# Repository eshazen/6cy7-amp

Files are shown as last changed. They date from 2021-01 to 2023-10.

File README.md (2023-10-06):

# 6CY7-amp

This is a low power single-ended tridode (SET) hi-fi amp for the
workshop.  It is essentially a build of the Cascade Tubes "Zebrawood"
amp: https://www.cascadetubes.com/the-6cy7-v2-0-zebrawood-amp/.  I'm
using transformers from MusicalPowerSupplies.com.

PCB design here is 388 x 194mm.  It's the standard 1oz copper, 1.6mm thick.
Everything is on the PCB.  Mounted on a wooden base on 3/4 inch standoffs (including standoffs under the PT).  Case is 20mm 80/20 T-slot rail with acrylic side panels.  Complete overkill, but I like the industrial look!

<table>
  <tr><td>
    <img src="https://github.com/eshazen/6cy7-amp/blob/main/pix/enclosure_done.jpg" width=500">
  <tr><td>

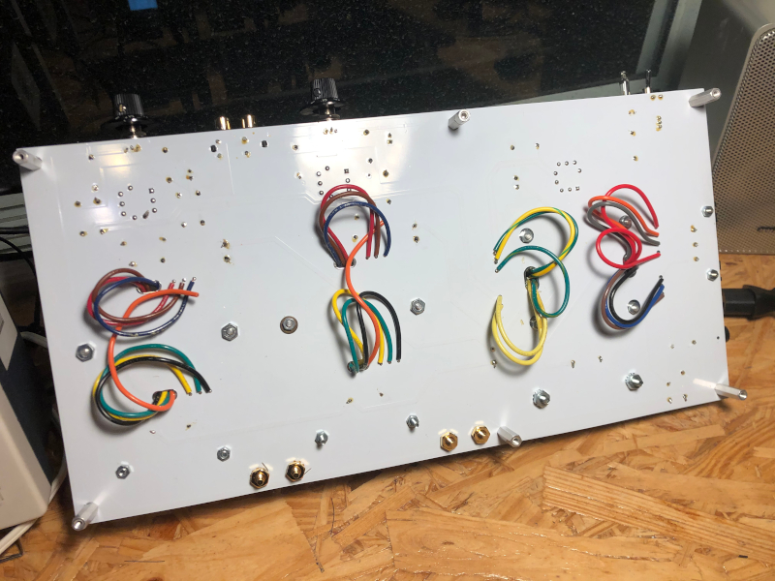
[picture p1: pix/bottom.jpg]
  
  <td>


</table>

## Want to build one?

See https://github.com/eshazen/6cy7-amp/blob/main/BuildNotes.md

## News

**2021-02-20**

Working on a second PCB.  MPS has a long lead time on the PT.  
Ordered two OT8SE OTs and one of these:  AS-1T175 -- (2x 175V @ 280mA, 2x 6.3V @ 3A).
This thing is toroidal, 3.9" dia, 2" h.  Plan to mount it vertically on a bracket above the PCB.

**2021-01-15**

It's done!  Sounds great!  A couple of concerns:

I forgot the R/C filter for the preamp stage B+.  No audible defects due to this, but if someone else wants
to consider using this PCB design the R+C should be added.

One of the "NOS" 6CY7s (a Tung-Sol, made in USA) ran very hot (right at 32mA, 5.4W plate diss.) with
the 1k cathode resistor.  Swapped it for another of indeterminate make and it is fine.  Both channels
now around 27mA (4.6W).

**2021-01-03**

* 2/29/20: Iron ordered from MusicalPowerSupplies.com for a ~ 1/15/21 ship date
* 1/2/21: Parts ordered from DigiKey and Antique Electronic Supply
* 1/3/21: PCBs ordered from JLC (white soldermask, black silkscreen, cool, eh?)

Total spent with some spare stuff thrown in ~ US $350.00.  Hope to have it running by end of January!

**Speakers** Need some small bookshelf speakers to go with it.  Will test the amp with what I have lying around before making any decisions.  The easiest would be to buy another pair of Minimus-7's and apply the 'Zilch' crossover mod.

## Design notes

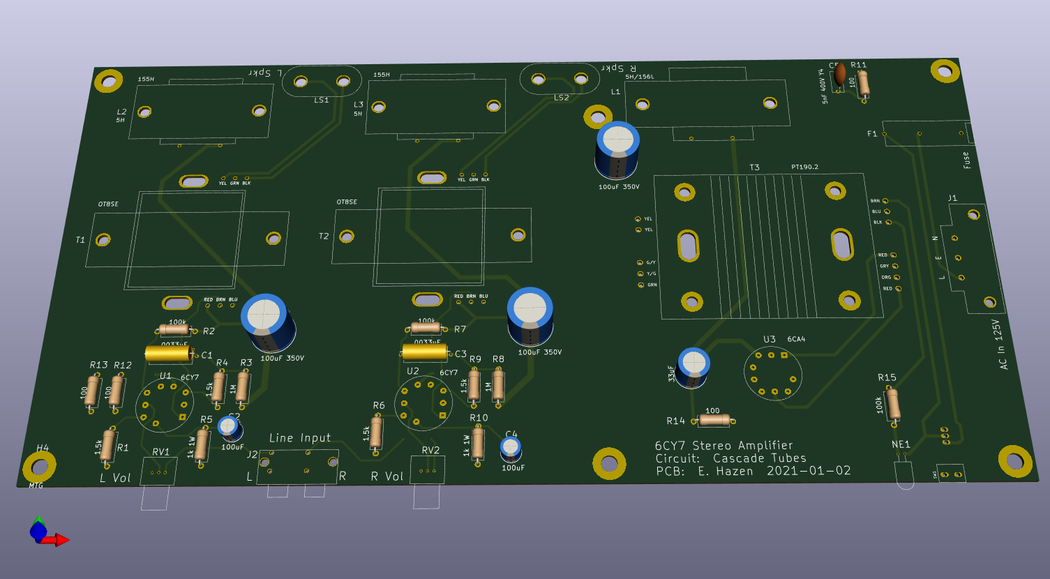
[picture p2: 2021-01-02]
pix/pcb_3d_amp.png

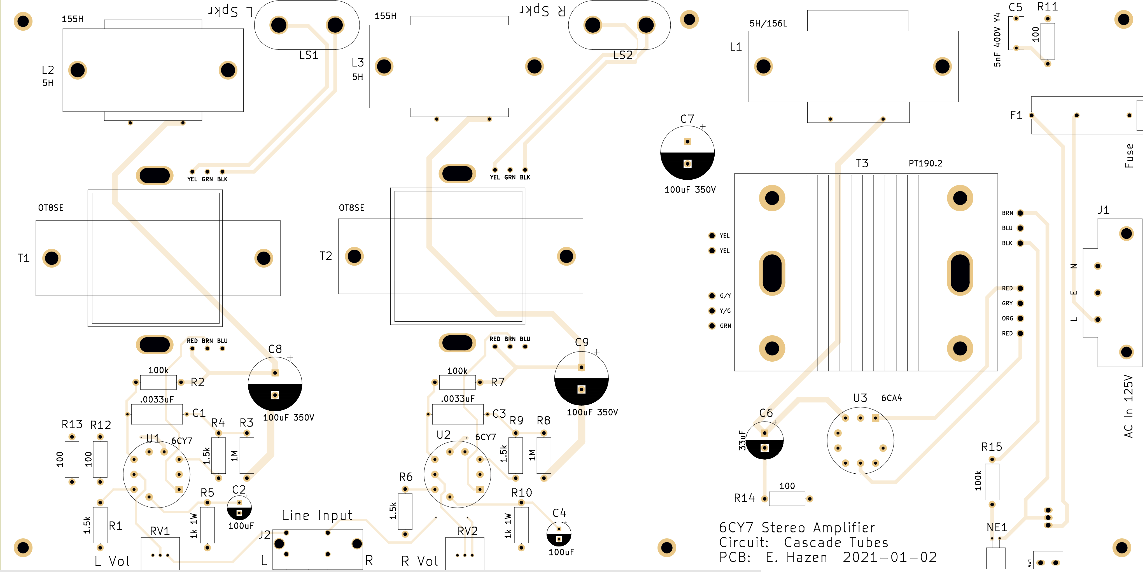
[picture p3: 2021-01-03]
pix/layout_preview.png

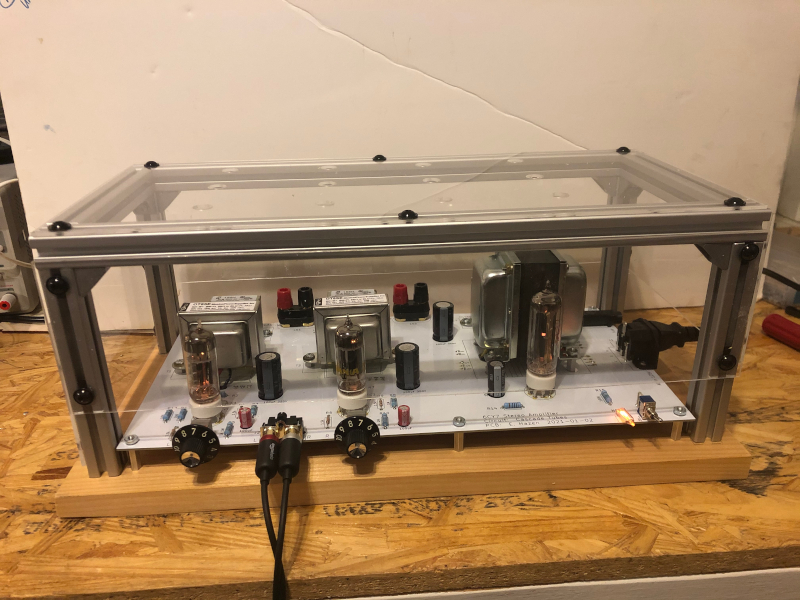
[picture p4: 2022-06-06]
pix/enclosure_done.jpg

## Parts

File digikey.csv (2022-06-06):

Quan | P/N | Ref
3 | Socket_P-ST9-221G | U1 U2
2 | Socket_P-ST9-221G | U3
3 | 1572-1715-ND | C1 C3
3 | 732-8666-1-ND | C2 C4
2 | 125LD50-R-ND | C5
2 | 493-12996-1-ND | C6
4 | 1189-4068-ND | C7 C8 C9
2 | 283-2709-ND | F1
2 | 486-1007-ND | J1
2 | SC1858-ND | J2
2 | HM3516-ND | L1
3 | 36-4109-ND | LS1 LS2
2 | A1A-ND | NE1
5 | BC4520CT-ND | R1 R4 R6 R9
5 | BC4517CT-ND | R11 R12 R13 R14
4 | BC4520CT-ND | R2 R7 R15
3 | BC4521CT-ND | R3 R8
3 | BC4518CT-ND | R5 R10
3 | 987-1330-ND | RV1 RV2
2 | 563-1727-ND | SW1

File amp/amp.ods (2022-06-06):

Reference | Quantity | Value | Footprint | Datasheet | CatNo | Vendor | Quan | P/N | Ref
U1 U2 | 2 | 6CY7 | Valve:Valve_Noval_P |  | Socket_P-ST9-221G | AES | 3 | Socket_P-ST9-221G | U1 U2
U3 | 1 | 6CA4 | Valve:Valve_Noval_P |  | Socket_P-ST9-221G | AES | 2 | Socket_P-ST9-221G | U3
C1 C3 | 2 | .0033uF | Capacitor_THT:C_Axial_L17.0mm_D6.5mm_P20.00mm_Horizontal | ~ | 1572-1715-ND | DigiKey | 2 | 1572-1715-ND | C1 C3
C2 C4 | 2 | 100uF | Capacitor_THT:CP_Radial_D8.0mm_P3.50mm | ~ | 732-8666-1-ND | DigiKey | 2 | 732-8666-1-ND | C2 C4
C5 | 1 | 5nF 400V Y4 | Capacitor_THT:C_Disc_D11.0mm_W5.0mm_P10.00mm | ~ | 125LD50-R-ND | DigiKey | 1 | 125LD50-R-ND | C5
C6 | 1 | 33uF | Capacitor_THT:CP_Radial_D12.5mm_P5.00mm | ~ | 493-12996-1-ND | DigiKey | 2 | 493-12996-1-ND | C6
C7 C8 C9 | 3 | 100uF 350V | Capacitor_THT:CP_Radial_D18.0mm_P7.50mm | ~ | 1189-4068-ND | DigiKey | 4 | 1189-4068-ND | C7 C8 C9
F1 | 1 | Fuse | HBH_fuse_holder:HBH-I-R | ~ | 283-2709-ND | DigiKey | 2 | 283-2709-ND | F1
J1 | 1 | Conn_01x05 | GSP1_power_entry:GSP1.8101.1 | ~ | 486-1007-ND | DigiKey | 2 | 486-1007-ND | J1
J2 | 1 | DUAL_RCA | RCA_jack:PJRAS2X1S01AUX |  | SC1858-ND | DigiKey | 2 | SC1858-ND | J2
L1 | 1 | 5H/156L | Hammond-L:156L | ~ | HM3516-ND | DigiKey | 2 | HM3516-ND | L1
L2 L3 | 2 | 5H | Hammond-L:155H | ~ | HM3512-ND | DigiKey | 3 | HM3512-ND | L2 L3
LS1 LS2 | 2 | Speaker | BindingPost:Keystone_4109 | ~ | 36-4109-ND | DigiKey | 3 | 36-4109-ND | LS1 LS2
NE1 | 1 | A1A | neon:A1A | ~ | A1A-ND | DigiKey | 2 | A1A-ND | NE1
R1 R4 R6 R9 | 4 | 1.5k | Resistor_THT:R_Axial_DIN0414_L11.9mm_D4.5mm_P15.24mm_Horizontal | ~ | BC4526CT-ND | DigiKey | 5 | BC4526CT-ND | R1 R4 R6 R9
R11 R12 R13 R14 | 4 | 100 | Resistor_THT:R_Axial_DIN0414_L11.9mm_D4.5mm_P15.24mm_Horizontal | ~ | BC4517CT-ND | DigiKey | 5 | BC4517CT-ND | R11 R12 R13 R14
R2 R7 R15 | 3 | 100k | Resistor_THT:R_Axial_DIN0414_L11.9mm_D4.5mm_P15.24mm_Horizontal | ~ | BC4520CT-ND | DigiKey | 4 | BC4520CT-ND | R2 R7 R15
R3 R8 | 2 | 1M | Resistor_THT:R_Axial_DIN0414_L11.9mm_D4.5mm_P15.24mm_Horizontal | ~ | BC4521CT-ND | DigiKey | 3 | BC4521CT-ND | R3 R8
R5 R10 | 2 | 1k 1W | Resistor_THT:R_Axial_DIN0414_L11.9mm_D4.5mm_P15.24mm_Horizontal | ~ | BC4518CT-ND | DigiKey | 3 | BC4518CT-ND | R5 R10
RV1 RV2 | 2 | 100k_audio | POT:P260P-D1BS3CA | ~ | 987-1330-ND | DigiKey | 3 | 987-1330-ND | RV1 RV2
SW1 | 1 | SW_SPST_GND | Switch_8GA:8GA1016-Z | ~ | 563-1727-ND | DigiKey | 2 | 563-1727-ND | SW1
H1 H2 H3 H4 H5 H6 | 6 | MTG | MountingHole:MountingHole_6.4mm_M6_Pad | ~ |  |  | 7 | 0 | H1 H2 H3 H4 H5 H6
T1 T2 | 2 | Transformer_1P_1S | OT8SE:OT8SE | ~ | OT8SE |  | 3 | OT8SE | T1 T2
T3 | 1 | Transformer_PT190.2 | PT190_2:PT190_2 | ~ |  |  | 2 | 0 | T3
Notes:
2/13/21 – Fix CatNo for R1… for 1.5K

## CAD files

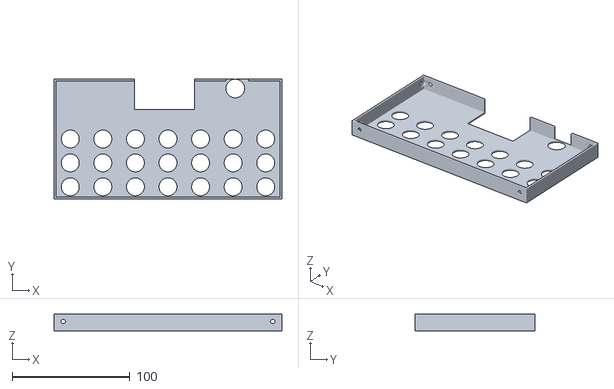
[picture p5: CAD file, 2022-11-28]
case/right_side.stl
193.7 x 101.6 x 14.2

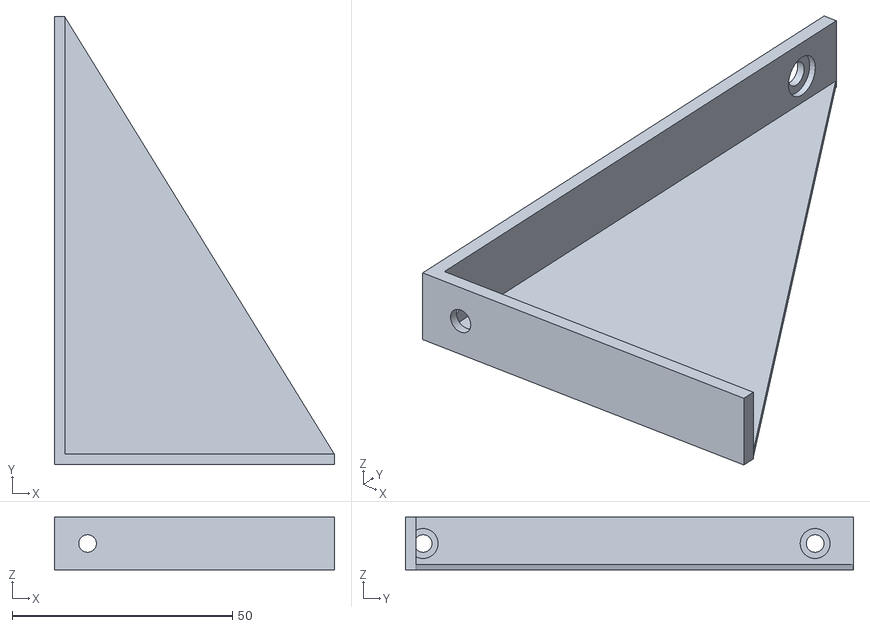
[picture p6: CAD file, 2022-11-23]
case/bracket4.stl
63.5 x 101.6 x 12.0

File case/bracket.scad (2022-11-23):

//
// mounting bracket for Olof's front panel (need 2)
//


e = 0.1;
$fn = 32;

mm = 25.4;

pcb_setback = 7.5;			/* PCB hole from edge */
front_raise = 4.0;			/* panel hole from top surf of pcb */
hole_dia = 4.0;
head_dia = 6.8;			/* 6-32 screw head diameter */

head_dep = 2;			/* relief depth */

front_space = 3.5*mm;		/* front panel hole spacing */

bracket_wid = 12;
bracket_thk = 2.4;
side_thk = 1.2;

// short version for test print
// bracket_pcb_len = 1*mm;	/* length along pcb */
// bracket_panel_hgt = 1*mm;	/* height behind panel */

bracket_pcb_len = 2.5*mm;	/* length along pcb */
bracket_panel_hgt = 4.0*mm;	/* height behind panel */

module base() {

     cube( [bracket_pcb_len, bracket_thk, bracket_wid]);
     cube( [bracket_thk, bracket_panel_hgt, bracket_wid]);

     linear_extrude( height=side_thk, center=false, convexity=10) {
	  polygon( [[bracket_pcb_len, bracket_thk-e],
		   [bracket_thk-e, bracket_panel_hgt],
		   [0,0]]);
     }
}


module bracket() {

     difference() {
//     {
	  base();

	  // home for PCB mount
	  translate( [pcb_setback, -e, bracket_wid/2]) {
	       rotate( [-90, 0, 0]) {
		    cylinder( d=hole_dia, h=10);
		    translate( [0, 0, 1.6]) {
			 $fn = 6;
			 cylinder( d=9, h=head_dep+bracket_thk/2);
		    }
	       }
	  }

	  // hole for FP mount
	  translate( [bracket_thk+e, front_raise, bracket_wid/2]) {
	       rotate( [-90, 0, 90]) {
		    cylinder( d=hole_dia, h=10);
		    translate( [0, 0, -head_dep])
		    cylinder( d=head_dia, h=head_dep+bracket_thk/2);
	       }
	  }

	  // hole for FP mount
	  translate( [bracket_thk+e, front_raise+front_space, bracket_wid/2]) {
	       rotate( [-90, 0, 90]) {
		    cylinder( d=hole_dia, h=10);
		    translate( [0, 0, -head_dep])
		    cylinder( d=head_dia, h=head_dep+bracket_thk/2);
	       }
	  }


     }
}

bracket();

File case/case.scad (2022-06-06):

// dimensions
wid = 16;
dep = 8;
hgt = 7;

fb_hgt = 5;

base_thk = 0.25;
side_thk = 0.125;

// bottom
color("brown") cube( [wid, dep, base_thk]);

// ends
rotate( [0, 270, 0]) {
     color("peru") cube( [hgt, dep, side_thk]);
     translate( [0, 0, -(wid+side_thk) ])
     color("peru") cube( [hgt, dep, side_thk]);
}

rotate( [90, 0, 0]) {
     translate( [-side_thk, 0, 0])
     %cube( [wid+2*side_thk, fb_hgt, side_thk]);
     translate( [-side_thk, 0, -(dep+side_thk) ])
     %cube( [wid+2*side_thk, fb_hgt, side_thk]);
}

translate( [-side_thk, 0, hgt])
 %cube( [wid+2*side_thk, dep, side_thk]);

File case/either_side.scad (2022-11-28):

//
// ventilated side panel
// printed right side 11/27/22 - fits OK
//

// select right/left side
right = 0;

e = 0.1;
mm = 25.4;
$fn = 37;

function frc( w, n, d) = (mm*(w + (n/d)));

side_wid = frc( 7, 5, 8);
side_hgt = 4*mm;

hole_spc = 7*mm;
hole_pos = (side_wid-hole_spc)/2;

lip_wid = 0.5*mm;
hole_off = 0.25*mm;
hole_dia = 0.15*mm;

side_thk = 1.6;

module body() {
     cube( [side_wid, side_hgt, side_thk]);
     translate( [0, 0, side_thk-e]) {
	       cube( [side_wid, side_thk, lip_wid]);
	       translate( [0, side_hgt-side_thk, 0])
		    cube( [side_wid, side_thk, lip_wid]);
	       cube( [side_thk, side_hgt, lip_wid]);
	       translate( [side_wid-side_thk, 0, 0])
		    cube( [side_thk, side_hgt, lip_wid]);
     }
}

front_raise = 4.0;			/* panel hole from top surf of pcb */
//hole_dia = 4.0;
head_dia = 6.8;			/* 6-32 screw head diameter */

head_dep = 2;			/* relief depth */

front_space = 3.5*mm;		/* front panel hole spacing */

bracket_wid = lip_wid;

module side() {

     difference()
     {
	  body();

	  // hole for FP mount
	  translate( [side_thk+e, front_raise, bracket_wid/2+side_thk]) {
	       rotate( [-90, 0, 90]) {
		    cylinder( d=hole_dia, h=10);
		    translate( [0, 0, -head_dep])
		    cylinder( d=head_dia, h=head_dep+side_thk/2);
	       }
	  }

	  // hole for FP mount
	  translate( [side_thk+e, front_raise+front_space, bracket_wid/2+side_thk]) {
	       rotate( [-90, 0, 90]) {
		    cylinder( d=hole_dia, h=10);
		    translate( [0, 0, -head_dep])
		    cylinder( d=head_dia, h=head_dep+side_thk/2);
	       }
	  }



	  // screw holes for PCB mount
	  translate( [hole_pos, -e, side_thk+hole_off]) {
	       rotate( [270, 0, 0]) {
		    cylinder( h=side_hgt+2*e, d=hole_dia);
		    translate( [0, 0, side_thk/2]) {
			 $fn = 6;
			 cylinder( d=9, h=head_dep+side_thk/2);
		    }
	       }
	  }

	  translate( [side_wid-hole_pos, -e, side_thk+hole_off]) {
	       rotate( [270, 0, 0]) {
		    cylinder( h=side_hgt+2*e, d=hole_dia);
		    translate( [0, 0, side_thk/2]) {
			 $fn = 6;
			 cylinder( d=9, h=head_dep+side_thk/2);
		    }
	       }
	  }

	  if( right) {

	       // power cutout
	       pc_x = 68.5;
	       pc_w = 51.0;

	       translate( [pc_x, -e, -e]) {
		    cube( [pc_w, 26, lip_wid+side_thk+2*e]);
	       }

	       // fuse - cutout
	       translate( [frc(5,3,4), -e, side_thk])
		    cube( [frc(0,3,4), side_thk+2*e, side_wid+e]);
	       // fuse - hole
	       translate( [frc(6,1,16), frc(0,5,8)/2, -e])
		    cylinder( h=side_thk+2*e, d=frc(0,5,8));
	  }

	  // vent holes
	  vent_dia = 0.6*mm;
	  vent_nx = 7;
	  vent_dx = side_wid / vent_nx;

	  vent_ny = 5;
	  vent_dy = side_hgt / vent_ny;
	  
	  for( y=[2:vent_ny]) {
	       translate( [0, vent_dy/2 + y*vent_dy, 0])
	       for( x=[0:vent_nx] ) {
		    translate( [vent_dx/2 + x*vent_dx, 0, -e])
			 cylinder( h=2*e+side_thk, d=vent_dia);
	       }
	  }

     }

}


// projection()

if( right) {
     rotate( [180, 0, 0])
	  mirror( v= [0, 0, 1]) {
	  side();
     }
} else {
     side();
}

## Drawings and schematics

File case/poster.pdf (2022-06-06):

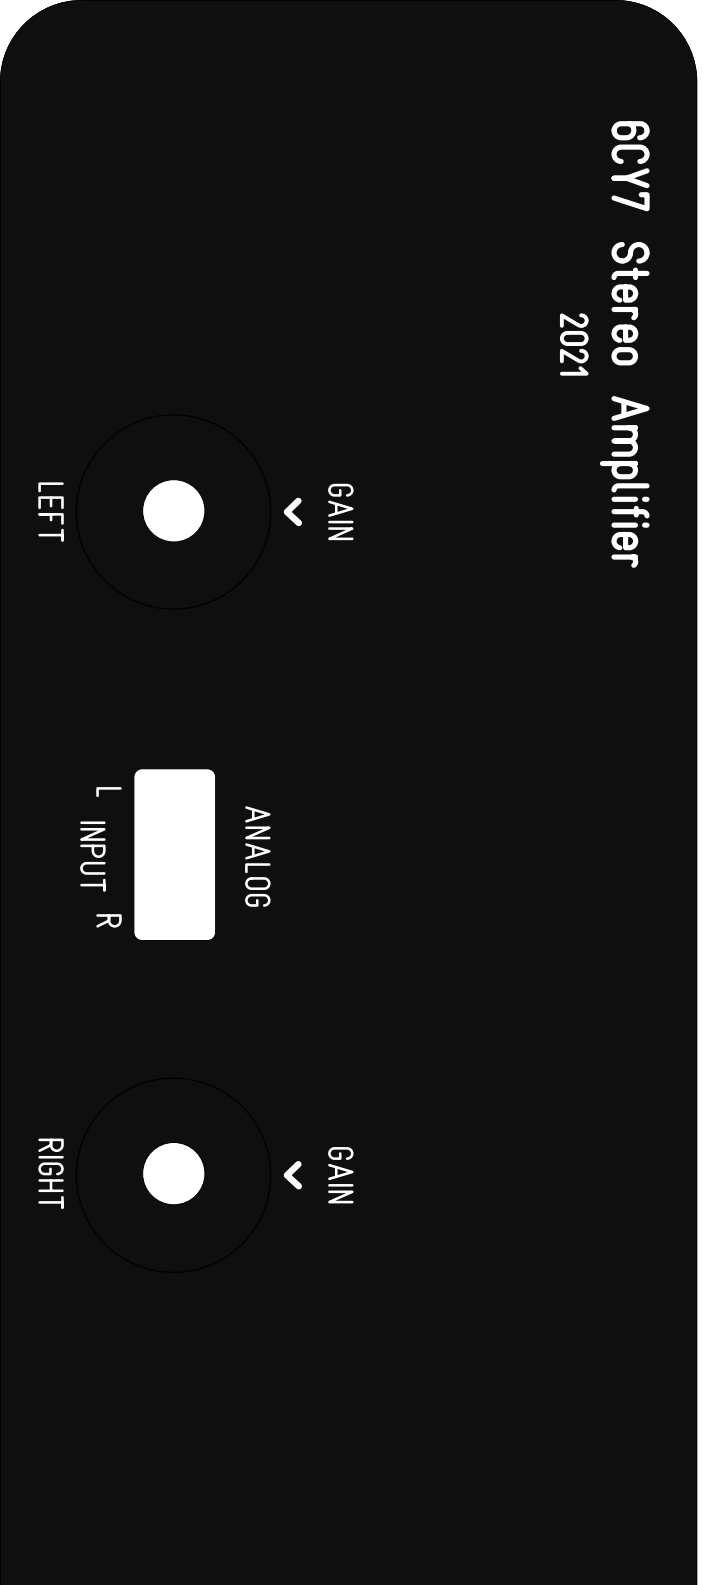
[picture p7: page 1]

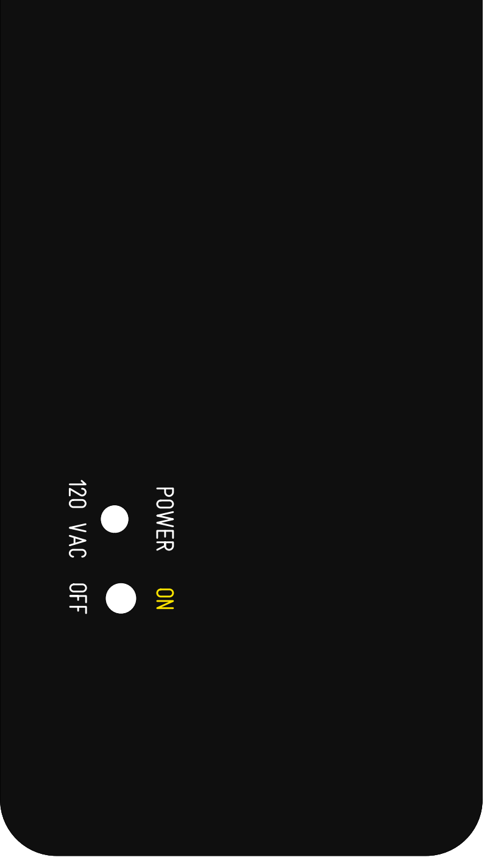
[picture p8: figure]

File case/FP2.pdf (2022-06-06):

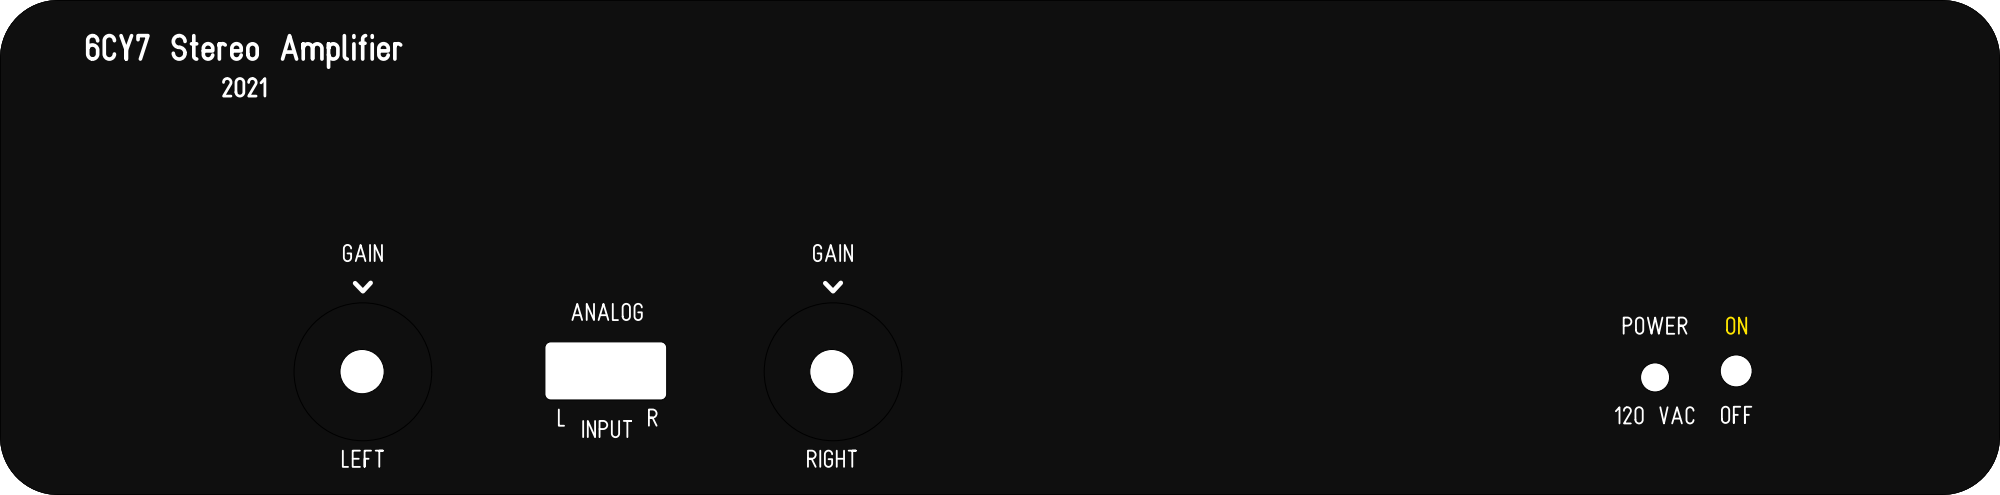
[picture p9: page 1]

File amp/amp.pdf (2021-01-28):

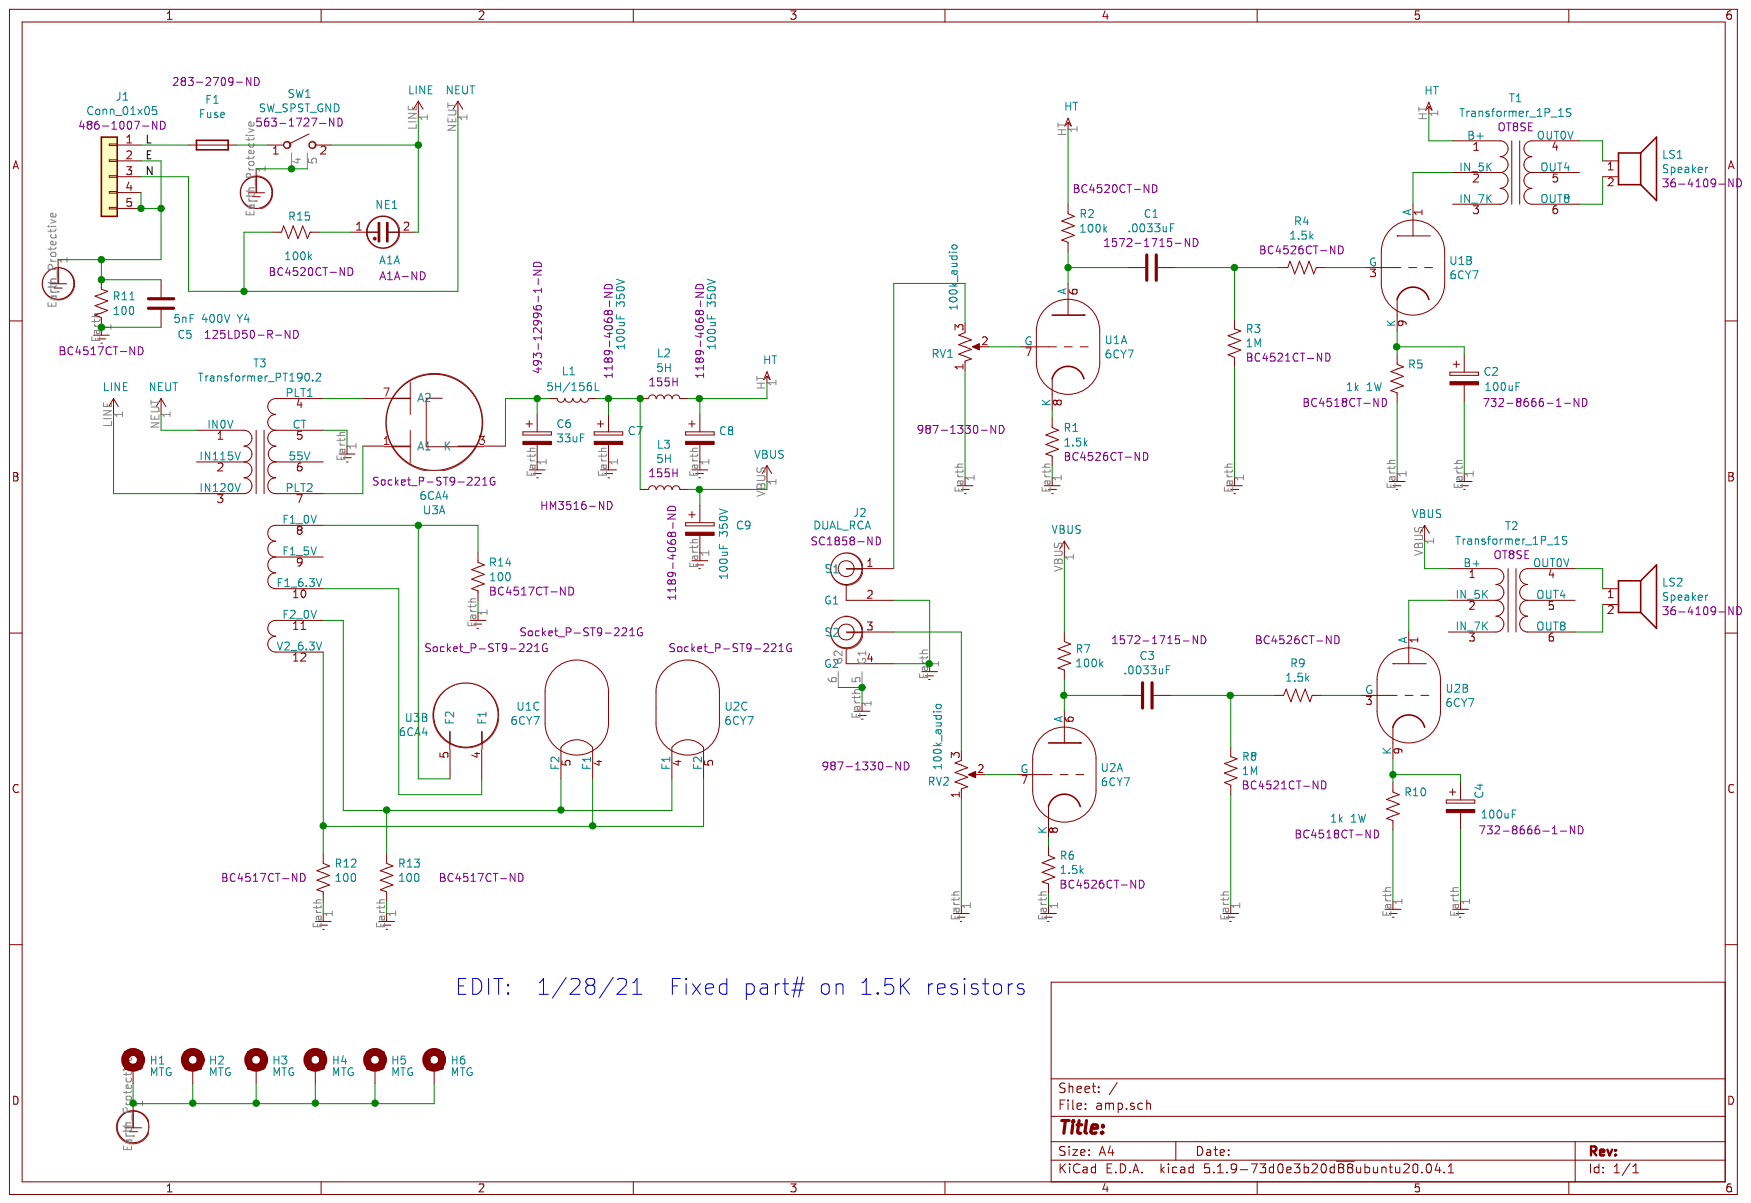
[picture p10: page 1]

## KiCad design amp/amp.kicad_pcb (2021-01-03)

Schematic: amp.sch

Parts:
C1, C3: .0033uF; C_Axial_L17.0mm_D6.5mm_P20.00mm_Horizontal
C2, C4: 100uF; CP_Radial_D8.0mm_P3.50mm
C5: 5nF 400V Y4; C_Disc_D11.0mm_W5.0mm_P10.00mm
C6: 33uF; CP_Radial_D12.5mm_P5.00mm
C7, C8, C9: 100uF 350V; CP_Radial_D18.0mm_P7.50mm
F1: Fuse; HBH-I-R
H1, H2, H3, H4, H5, H6: MTG; MountingHole_6.4mm_M6_Pad
J1: Conn_01x05; GSP1.8101.1
J2: DUAL_RCA; PJRAS2X1S01AUX
L1: 5H/156L; 156L
L2, L3: 5H; 155H
LS1, LS2: Speaker; Keystone_4109
NE1: A1A
R1, R4, R6, R9: 1.5k; R_Axial_DIN0414_L11.9mm_D4.5mm_P15.24mm_Horizontal
R2, R7, R15: 100k; R_Axial_DIN0414_L11.9mm_D4.5mm_P15.24mm_Horizontal
R3, R8: 1M; R_Axial_DIN0414_L11.9mm_D4.5mm_P15.24mm_Horizontal
R5, R10: 1k 1W; R_Axial_DIN0414_L11.9mm_D4.5mm_P15.24mm_Horizontal
R11, R12, R13, R14: 100; R_Axial_DIN0414_L11.9mm_D4.5mm_P15.24mm_Horizontal
RV1, RV2: 100k_audio; P260P-D1BS3CA
SW1: SW_SPST_GND; 8GA1016-Z
T1, T2: Transformer_1P_1S; OT8SE
T3: Transformer_PT190.2; PT190_2
U1, U2: 6CY7; Valve_Noval_P
U3: 6CA4; Valve_Noval_P

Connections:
/L: F1.2, J1.1
Earth: C2.2, C4.2, C5.1, C6.2, C7.2, C8.2, C9.2, J2.2 (G1), J2.4 (G2), J2.5, J2.6, R1.2, R3.2, R5.2, R6.2, R8.2, R10.2, R11.2, R12.2, R13.2, R14.2, RV1.1, RV2.1, T3.5 (CT)
Earth_Protective: C5.2, H1.1, H2.1, H3.1, H4.1, H5.1, H6.1, J1.2, J1.4, J1.5, R11.1, SW1.4, SW1.5
HT: C8.1, L2.2, R2.1, T1.1
LINE: NE1.2, SW1.2, T3.3 (IN120V)
NEUT: J1.3, R15.2, T3.1 (IN0V)
unnamed: C1.1, R3.1, R4.2
unnamed: C1.2, R2.2, U1.6 (A)
unnamed: C2.1, R5.1, U1.9 (K)
unnamed: C3.1, R8.1, R9.2
unnamed: C3.2, R7.2, U2.6 (A)
unnamed: C4.1, R10.1, U2.9 (K)
unnamed: C6.1, L1.2, U3.3 (K)
unnamed: C7.1, L1.1, L2.1, L3.1
unnamed: F1.1, SW1.1
unnamed: J2.1 (S1), RV1.3
unnamed: J2.3 (S2), RV2.3
unnamed: LS1.1, T1.4
unnamed: LS1.2, T1.6
unnamed: LS2.1, T2.4
unnamed: LS2.2, T2.6
unnamed: NE1.1, R15.1
unnamed: R1.1, U1.8 (K)
unnamed: R4.1, U1.3 (G)
unnamed: R6.1, U2.8 (K)
unnamed: R9.1, U2.3 (G)
unnamed: R12.1, T3.12 (V2_6.3V), U1.4 (F1), U2.5 (F2)
unnamed: R13.1, T3.11 (F2_0V), U1.5 (F2), U2.4 (F1)
unnamed: R14.1, T3.8 (F1_0V), U3.5 (F2)
unnamed: RV1.2, U1.7 (G)
unnamed: RV2.2, U2.7 (G)
unnamed: T1.2, U1.1 (A)
unnamed: T2.2, U2.1 (A)
unnamed: T3.4 (PLT1), U3.7 (A2)
unnamed: T3.7 (PLT2), U3.1 (A1)
unnamed: T3.10 (F1_6.3V), U3.4 (F1)
VBUS: C9.1, L3.2, R7.1, T2.1

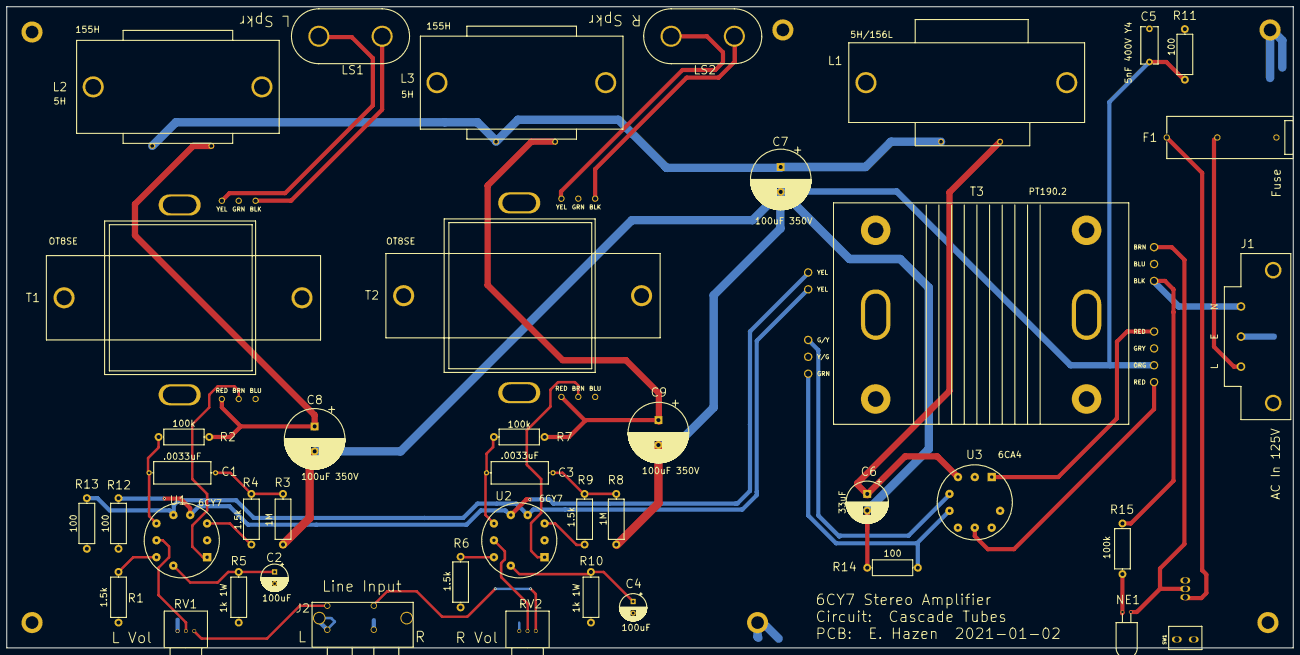
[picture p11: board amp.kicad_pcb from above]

Board: 2 copper layers, 387.4 x 193.0 mm, 48 parts (0 on the bottom side), 37 nets.

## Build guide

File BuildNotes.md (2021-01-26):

## Want to build one?

Contact Matt at musicalpowersupplies.com and ask for:

```
(1) PT190.2 USA   (or international version if not in USA)
(2) OT8SE
```
Then, order everything on the BOM:  https://github.com/eshazen/6cy7-amp/blob/main/amp/amp.ods

You need both tubes and sockets:

```
  (2) 6CY7 
  (1) EZ81/6CA4
  brand is unimportant, best get one spare of each
```

Sockets are on the BOM from AES (Antique Electronic Supply @ tubesandmore.com)

Other parts are mostly from Digikey

You will also want:

```
About 20 3/4" long 6-32 male/female standoffs
About 4 1/2" long 6-32 male/female standoffs
A good supply of 6-32 nuts and screws and maybe some washers
Some 1A slow-blo fuses (1-1/4" long glass ones)
An AC power cord
```

## Some assembly notes:

The tube sockets just sit on top of the PCB pads.  Bend the pins carefully so they sit in the center of each pad and use lots of solder.

The transformers mount on standoffs on the top, wires thread through the slots and terminate from the bottom.  Wire colors are on the silkscreen.  The orange wire on the OTs is not used.

I screwed the inductors (L1-L3) directly to the board, cut the wires short and soldered them in from the top.  Easier to solder the wires in first, then bolt down the inductors.

For the speaker outputs, the pads are too small to make good contact with the terminals.  I put a small piece of bare wire through each hole and then installed the terminals with the supplied nuts and lockwashers and tightened them.  You could also solder them in.

## Power-up procedure

***CAREFUL FOR HIGH VOLTAGE!  DON'T TOUCH ANYTHING WITH YOUR BARE FINGERS WHEN IT'S ON!***

I have a rig with a variac and light bulb in series I use for all new amp power-ups.  If you are very careful to get all the parts in the right place and install a reasonable fuse you're probably OK to just turn it on and hope for the best.  

Here are some voltage measurements to check (GND is on for example the shield of the input jacks)

```
  B+             ~ 208V  (measure on "RED" solder pad next to each OT)
  Cathode bias:  ~ 28V   (measure across R5 and R10)
```

Don't operate the amp for any significant time with no speakers connected if you are feeding an input signal.  This can damage the output section.  An 8 ohm resistor rated a few W is a fine dummy load.

## Super-careful power-up procedure

```
  Install only the rectifier tube (U3, 6CA4/EZ81) 
  Solder temporary load resistors (10W 8-10k or so across C8 and C9 on the bottom)
  Power up with an incandescent light bulb 40W-100W in series with the power cord
     (not a modern LED or CFL bulb)
  If the bulb lights, turn off and figure out what is wrong
  Measure B+ ("RED" solder pad next to each OT)
  It should come up to around 200V within 30s or so as the rectifier warms
  
  Power down, remove the load resistors, install the signal tubes (6CY7) one at a time
  Power up, watch the voltage across R5 or R10... should settle around 28V.
     If it is much different from this, turn off and debug
  Check voltage across R1 or R6, should be around 1.3V

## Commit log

2021-01-01 Working on PCB
    [amp.kicad_pcb, amp.sch]
2021-01-02 First try at placement
    [amp.kicad_pcb, amp.sch]
2021-01-02 save before branch
    [amp.kicad_pcb]
2021-01-02 First draft layout done
    [amp.kicad_pcb, amp.sch]
2021-01-02 Candidate for first build
    [amp-B_Cu.gbr, amp-B_Mask.gbr, amp-B_SilkS.gbr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]
2021-01-02 Change to 6-32 mounting holes
    [amp-B_Cu.gbr, amp-B_Mask.gbr, amp-B_SilkS.gbr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]
2021-01-03 Fix 156L footprint
    [amp-B_Cu.gbr, amp-B_Mask.gbr, amp-B_SilkS.gbr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]
2021-01-28 Fix 1.5K part number, add PDF schematic
    [amp.csv, amp.sch]
2022-06-06 library updates
    [amp.ods, case.scad, digikey.csv]
2022-11-23 front panel mounting bracket
    [bracket.scad, bracket4.stl]
2022-11-28 3D printed side panel
    [either_side.scad, right_side.stl]
